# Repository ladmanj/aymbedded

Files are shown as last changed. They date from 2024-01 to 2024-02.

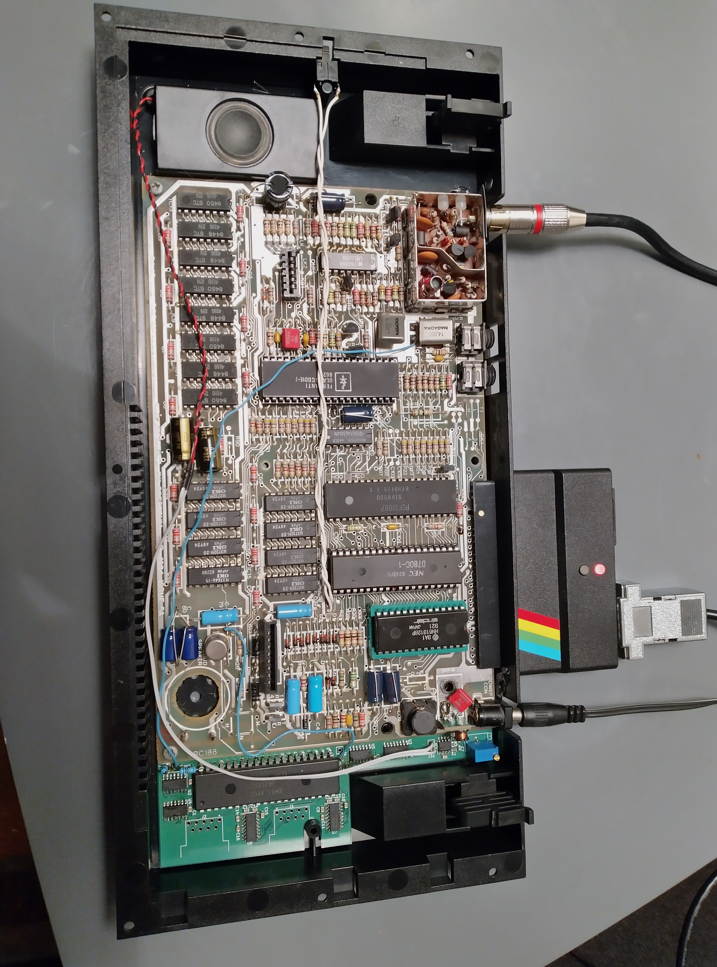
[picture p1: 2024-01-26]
connection_instructions/IMG_20240126_005043.jpg

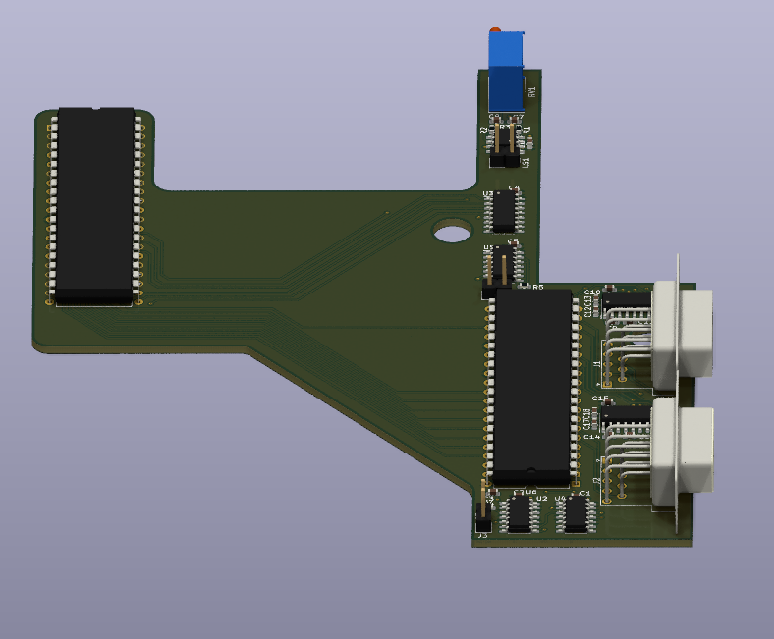
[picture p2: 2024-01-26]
connection_instructions/3d_render.png

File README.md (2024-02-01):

PCB for embed the AY-3-8910 and class-D amplifier into the ZX Spectrum+ case
2023/2024 Jakub Ladman
(ladmanj at volny cz)

For years I had a wire nest with a piece of protoboard for my AY-3-8910 (actually YM2149) that was very flimsy and prone to damage.
Last Christmas break I drew the PCB to put everything in the computer case.
The three PSG channels are mixed with the output of the SPKR ULA and the resulting signal is amplified by a class-D amplifier and sent to a reasonable quality loudspeaker.

All IOs used in the ZXS128k for serial ports are equipped with RS232 transceivers. The second IO port is connected directly to the optional connector.
These IO ports are not yet tested.

The PCB is soldered directly on the underside of the ZX Spectrum motherboard to the CPU pins.
The images are in the connection_instructions folder.

License: Do what you want. My support will be very limited, but feel free to ask me anything.

I have four blank PCBs. The first four of you can basically have it for the cost of shipping. Please contact me if you are interested.

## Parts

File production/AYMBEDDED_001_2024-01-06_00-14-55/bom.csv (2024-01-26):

Designator | Footprint | Quantity | Value | LCSC Part #
C1, C10, C15, C2, C3, C4, C5, C6 | 0603 | 8 | 1uF
C11, C12, C13, C14, C16, C17, C18, C7, C8, C9 | 0603 | 10 | 100n
IC1 | Diodes_SO-8EP | 1 | PAM8304ASR (CS8305E)
J1 | DSUB-9_Male_Horizontal_P2.77x2.54mm_EdgePinOffset9.40mm | 1 | DE9_Plug
J2 | DSUB-9_Female_Horizontal_P2.77x2.54mm_EdgePinOffset9.40mm | 1 | DE9_Receptacle
J3, J4 | PinHeader_1x02_P2.54mm_Vertical | 2 | Conn_01x02_Pin
LS1 | PinHeader_1x02_P2.54mm_Vertical | 1 | Speaker
R1, R2, R5, R6, R7 | 0603 | 5 | 300k
R3 | 0603 | 1 | 1k
R4 | 0603 | 1 | 22R
RV1 | Potentiometer_Bourns_3299Z_Horizontal | 1 | 10k
U1 | DIP-40_W15.24mm | 1 | jen motiv na desce
U2, U4 | SO-14_3.9x8.65mm_P1.27mm | 2 | 74HC74
U3 | SO-16_3.9x9.9mm_P1.27mm | 1 | 74HC138
U5 | SO-14_3.9x8.65mm_P1.27mm | 1 | 74HC132
U6 | DIP-40_W15.24mm | 1 | AY-3-8910 (YM2149)
U7, U8 | SO-16_3.9x9.9mm_P1.27mm | 2 | MAX3232

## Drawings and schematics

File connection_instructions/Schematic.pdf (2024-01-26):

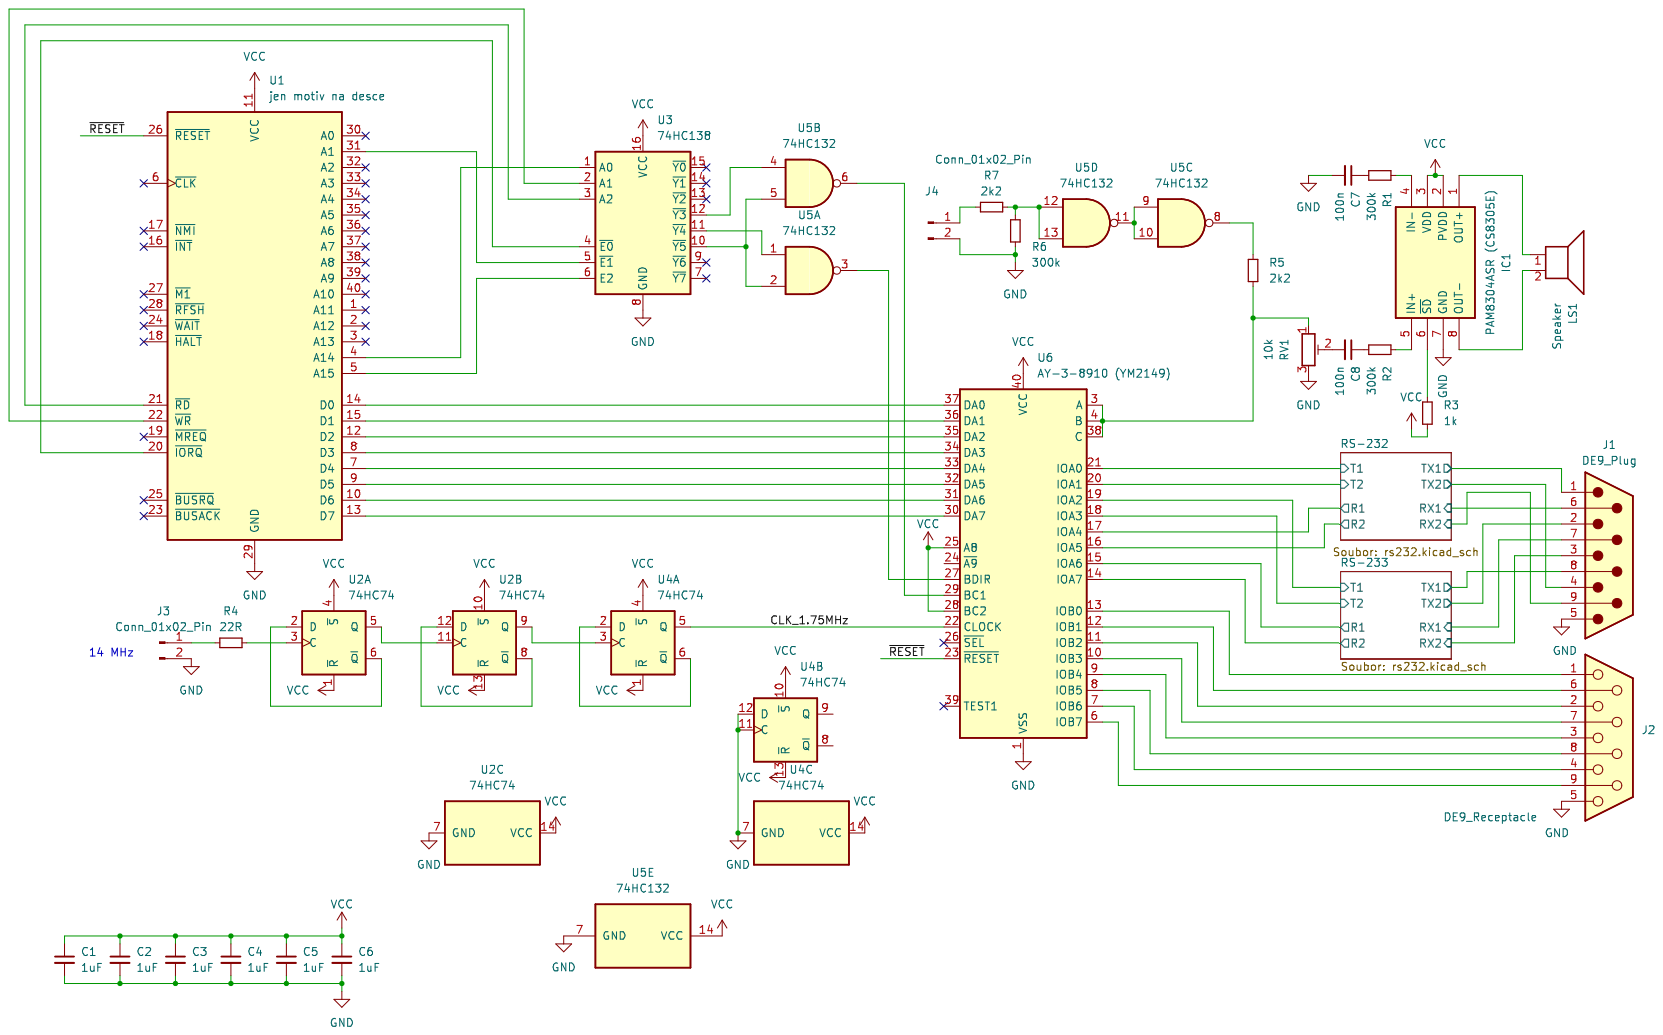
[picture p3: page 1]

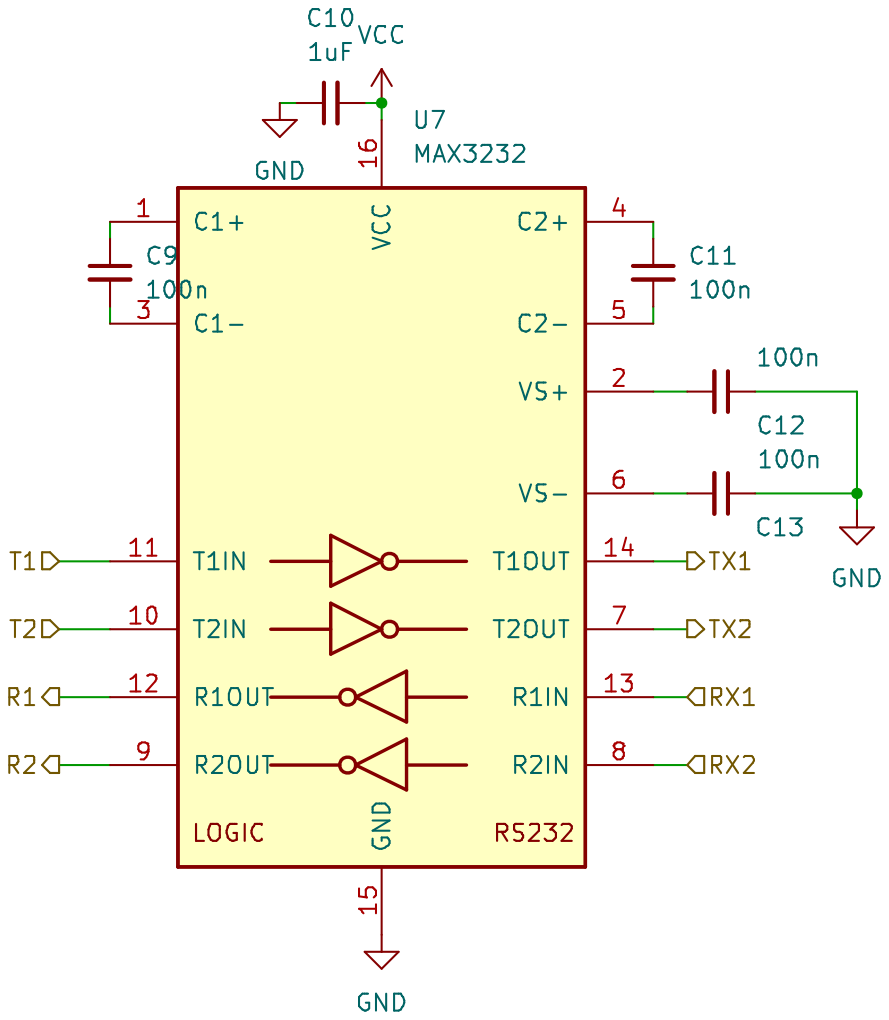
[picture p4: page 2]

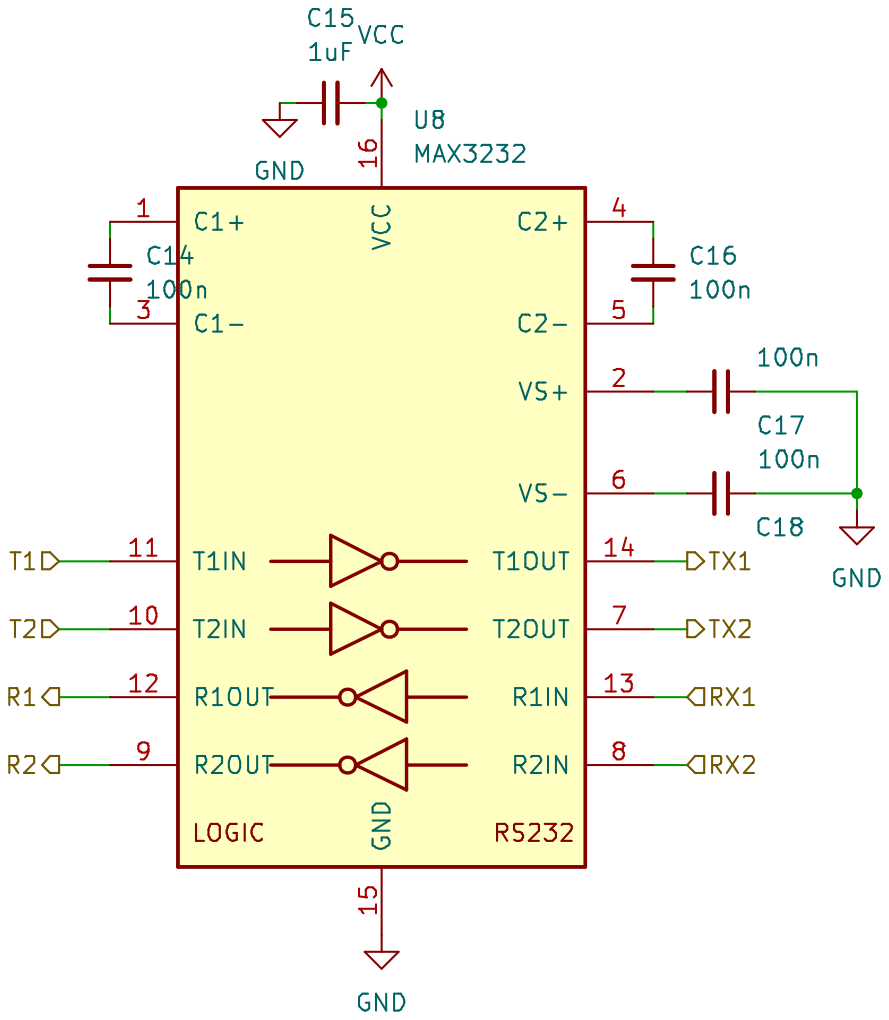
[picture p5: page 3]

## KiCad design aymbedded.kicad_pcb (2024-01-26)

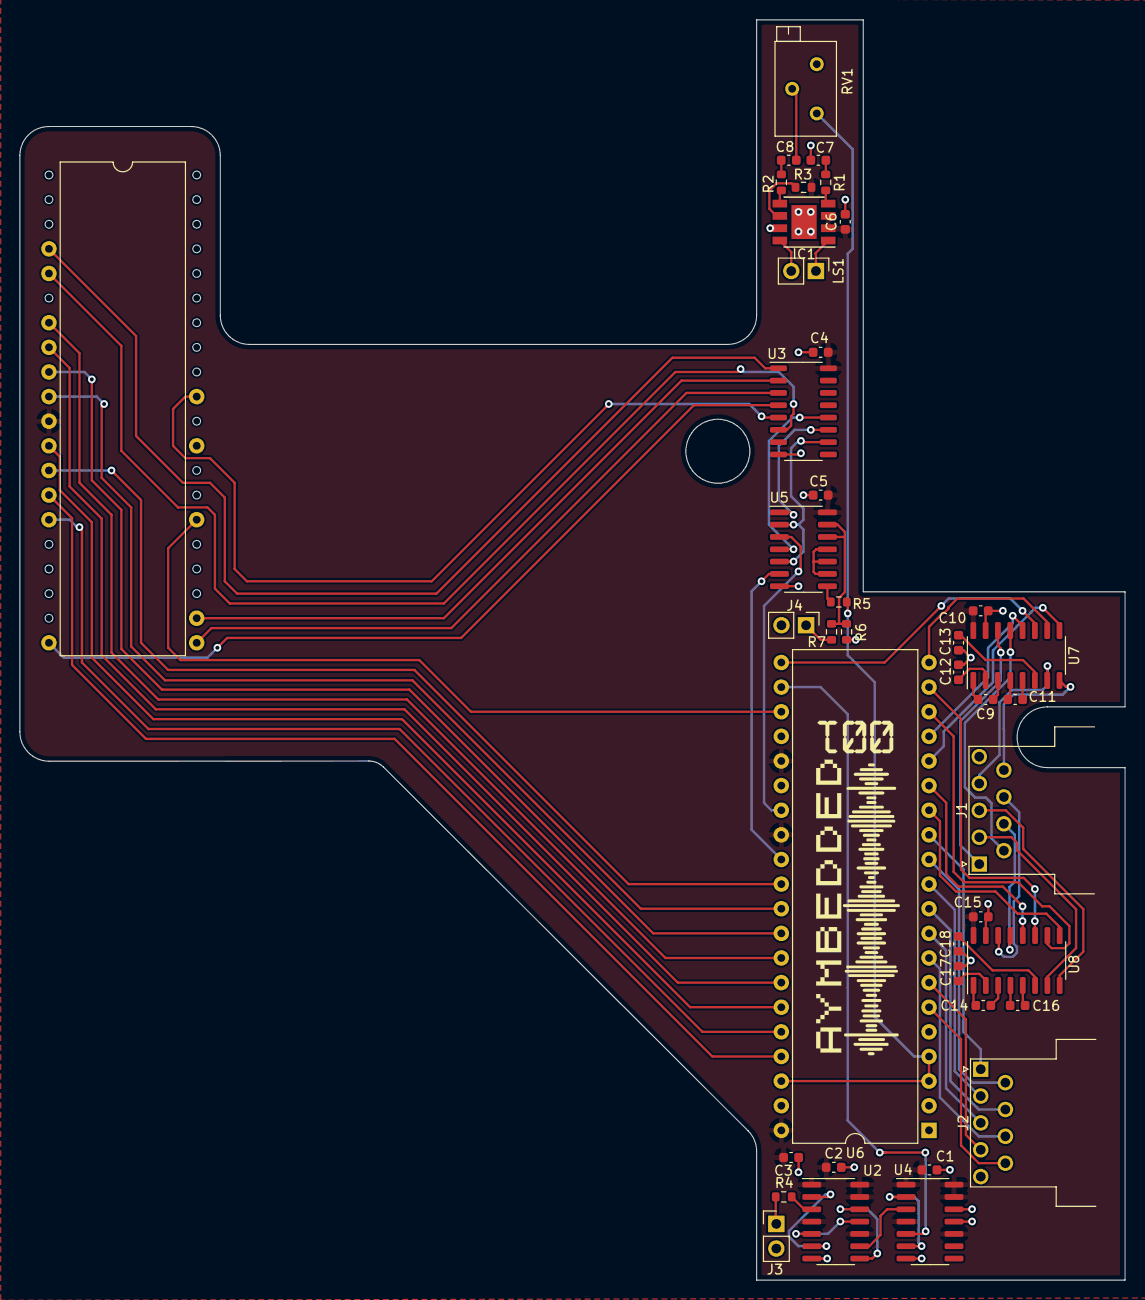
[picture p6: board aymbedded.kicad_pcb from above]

Board: 2 copper layers, 114.0 x 130.0 mm, 40 parts (0 on the bottom side), 79 nets.

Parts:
C1, C2, C3, C4, C5, C6, C10, C15: 1uF; C_0603_1608Metric
C7, C8, C9, C11, C12, C13, C14, C16, C17, C18: 100n; C_0603_1608Metric
IC1: PAM8304ASR (CS8305E); Diodes_SO-8EP
J1: DE9_Plug; DSUB-9_Male_Horizontal_P2.77x2.54mm_EdgePinOffset9.40mm
J2: DE9_Receptacle; DSUB-9_Female_Horizontal_P2.77x2.54mm_EdgePinOffset9.40mm
J3, J4: Conn_01x02_Pin; PinHeader_1x02_P2.54mm_Vertical
LS1: Speaker; PinHeader_1x02_P2.54mm_Vertical
R1, R2, R5, R6, R7: 300k; R_0603_1608Metric
R3: 1k; R_0603_1608Metric
R4: 22R; R_0603_1608Metric
RV1: 10k; Potentiometer_Bourns_3299Z_Horizontal
U1: jen motiv na desce; DIP-40_W15.24mm
U2, U4: 74HC74; SO-14_3.9x8.65mm_P1.27mm
U3: 74HC138; SO-16_3.9x9.9mm_P1.27mm
U5: 74HC132; SO-14_3.9x8.65mm_P1.27mm
U6: AY-3-8910 (YM2149); DIP-40_W15.24mm
U7, U8: MAX3232; SO-16_3.9x9.9mm_P1.27mm

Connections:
/CLK_1.75MHz: U4.5 (Q), U6.22 (CLOCK)
/RS-232/R1: U6.17 (IOA4), U7.12 (R1OUT)
/RS-232/R2: U6.16 (IOA5), U7.9 (R2OUT)
/RS-232/RX1: J1.6, U7.13 (R1IN)
/RS-232/RX2: J1.9, U7.8 (R2IN)
/RS-232/T1: U6.21 (IOA0), U7.11 (T1IN)
/RS-232/T2: U6.20 (IOA1), U7.10 (T2IN)
/RS-232/TX1: J1.1, U7.14 (T1OUT)
/RS-232/TX2: J1.4, U7.7 (T2OUT)
/RS-233/R1: U6.15 (IOA6), U8.12 (R1OUT)
/RS-233/R2: U6.14 (IOA7), U8.9 (R2OUT)
/RS-233/RX1: J1.7, U8.13 (R1IN)
/RS-233/RX2: J1.3, U8.8 (R2IN)
/RS-233/T1: U6.19 (IOA2), U8.11 (T1IN)
/RS-233/T2: U6.18 (IOA3), U8.10 (T2IN)
/RS-233/TX1: J1.8, U8.14 (T1OUT)
/RS-233/TX2: J1.2, U8.7 (T2OUT)
/~RESET: U1.26 (~RESET), U6.23 (~RESET)
GND: C1.2, C2.2, C3.2, C4.2, C5.2, C6.2, C7.2, C10.1, C12.1, C13.1, C15.1, C17.1, C18.1, IC1.7 (GND), J1.5, J2.5, J3.2, J4.2, R6.1, RV1.3, U1.29 (GND), U2.7 (GND), U3.8 (GND), U4.7 (GND), U4.11 (C), U4.12 (D), U5.7 (GND), U6.1 (VSS), U7.15 (GND), U8.15 (GND)
unnamed: C7.1, R1.1
unnamed: C8.1, R2.1
unnamed: C8.2, RV1.2
unnamed: IC1.5 (IN+), R2.2
unnamed: IC1.4 (IN-), R1.2
unnamed: IC1.1 (OUT+), LS1.1
unnamed: IC1.8 (OUT-), LS1.2
unnamed: IC1.6 (~SD), R3.2
unnamed: J3.1, R4.2
unnamed: J4.1, R7.2
unnamed: R5.2, U5.8
unnamed: R6.2, R7.1, U5.12, U5.13
unnamed: U1.31 (A1), U3.5 (~E1)
unnamed: U1.4 (A14), U3.1 (A0)
unnamed: U1.5 (A15), U3.6 (E2)
unnamed: U1.14 (D0), U6.37 (DA0)
unnamed: U1.15 (D1), U6.36 (DA1)
unnamed: U1.12 (D2), U6.35 (DA2)
unnamed: U1.8 (D3), U6.34 (DA3)
unnamed: U1.7 (D4), U6.33 (DA4)
unnamed: U1.9 (D5), U6.32 (DA5)
unnamed: U1.10 (D6), U6.31 (DA6)
unnamed: U1.13 (D7), U6.30 (DA7)
unnamed: U1.20 (~IORQ), U3.4 (~E0)
unnamed: U1.21 (~RD), U3.3 (A2)
unnamed: U1.22 (~WR), U3.2 (A1)
unnamed: R4.1, U2.3 (C)
unnamed: U2.2 (D), U2.6 (~Q)
unnamed: U2.5 (Q), U2.11 (C)
unnamed: U2.8 (~Q), U2.12 (D)
unnamed: U2.9 (Q), U4.3 (C)
unnamed: U3.12 (~Y3), U5.4
unnamed: U3.11 (~Y4), U5.1
unnamed: U3.10 (~Y5), U5.2, U5.5
unnamed: U4.2 (D), U4.6 (~Q)
unnamed: U5.9, U5.10, U5.11
unnamed: R5.1, RV1.1, U6.3 (A), U6.4 (B), U6.38 (C)
unnamed: U5.6, U6.29 (BC1)
unnamed: U5.3, U6.27 (BDIR)
unnamed: J2.1, U6.13 (IOB0)
unnamed: J2.6, U6.12 (IOB1)
unnamed: J2.2, U6.11 (IOB2)
unnamed: J2.7, U6.10 (IOB3)
unnamed: J2.3, U6.9 (IOB4)
unnamed: J2.8, U6.8 (IOB5)
unnamed: J2.4, U6.7 (IOB6)
unnamed: J2.9, U6.6 (IOB7)
unnamed: C9.1, U7.1 (C1+)
unnamed: C9.2, U7.3 (C1-)
unnamed: C11.1, U7.4 (C2+)
unnamed: C11.2, U7.5 (C2-)
unnamed: C12.2, U7.2 (VS+)
unnamed: C13.2, U7.6 (VS-)
unnamed: C14.1, U8.1 (C1+)
unnamed: C14.2, U8.3 (C1-)
unnamed: C16.1, U8.4 (C2+)
unnamed: C16.2, U8.5 (C2-)
unnamed: C17.2, U8.2 (VS+)
unnamed: C18.2, U8.6 (VS-)
VCC: C1.1, C2.1, C3.1, C4.1, C5.1, C6.1, C10.2, C15.2, IC1.2 (PVDD), IC1.3 (VDD), R3.1, U1.11 (VCC), U2.1 (~R), U2.4 (~S), U2.10 (~S), U2.13 (~R), U2.14 (VCC), U3.16 (VCC), U4.1 (~R), U4.4 (~S), U4.10 (~S), U4.13 (~R), U4.14 (VCC), U5.14 (VCC), U6.25 (A8), U6.28 (BC2), U6.40 (VCC), U7.16 (VCC), U8.16 (VCC)

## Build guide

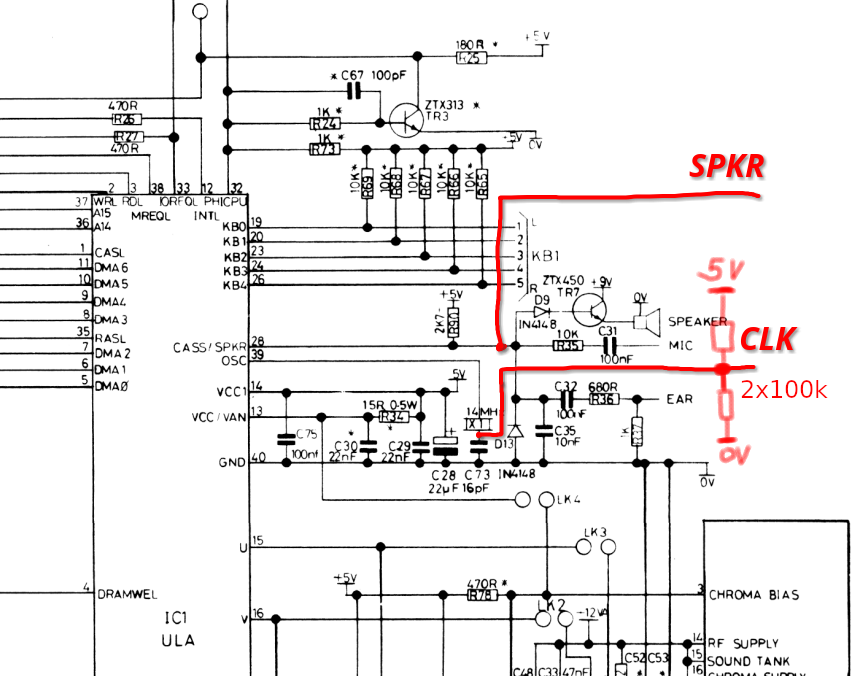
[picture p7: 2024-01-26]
connection_instructions/ZXS_ISS_6A.png

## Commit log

2024-01-26 PCB to embed AY-3-8910 and Class-D amplifier into ZX Spectrum+ case
2024-01-26 KiCAD 3D render added
2024-01-26 Schematic in pdf format added
